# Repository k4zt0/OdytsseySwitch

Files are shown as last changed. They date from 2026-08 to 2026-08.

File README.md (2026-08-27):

# Odytssey Switch

Five-key wireless macropad built around an ESP32-S3, with a 0.96" OLED and a
thumbstick. Reaches a host over USB HID, BLE HID, or Wi-Fi, and can drive other
gear through its I2C, UART and addressable-LED outputs.

## Hardware

| Block | Part |
| --- | ---- |
| MCU | ESP32-S3-WROOM-1 — BLE 5, Wi-Fi 4, native USB, pre-certified module |
| Keys | 5 x Kailh MX hotswap sockets on GPIO 4, 5, 6, 7, 15 |
| Stick | 2-axis thumbstick, X on IO1 and Y on IO2 (ADC1 only), press on IO16 |
| Display | SSD1306 0.96" 128x64 over I2C0 (SDA IO8, SCL IO9) |
| Outputs | Qwiic I2C port, WS2812 strip header, UART0 + 4 spare GPIO |
| Power | USB-C bus powered, AP2112K-3.3 LDO, USBLC6-2SC6 ESD array |

Both analogue axes sit on ADC1 because ADC2 stops working once the radio is
transmitting. The thumbstick is fed 3V3 rather than 5V so its wiper range
matches the ADC full scale.

## Board

- 112 x 102 mm, 2 layer FR-4, 1.6 mm, 3 mm corner radius
- Front carries the keys and the two module sockets; every other part is on the
  back, so the panel reflows from one side only
- No through-hole parts — the module connectors are SMD sockets, so assembly
  needs no soldering at all
- Routed on both layers, 345 tracks and 207 vias, ground pours stitched
  together and bonded solid to pads rather than through thermal spokes
- The ESP32 module's antenna overhangs the left edge; keep metal away from it
- Ground pours on both layers, stitched with vias

## Assembly

Order with SMT assembly. Nothing needs soldering afterwards:

1. Plug the OLED module into J2
2. Plug the thumbstick module into J7
3. Drop five MX switches into the hotswap sockets
4. Fit keycaps

Buy modules that already have their pin headers soldered on.

## Fabrication

`fab/` holds Gerbers, Excellon drill files, the drill map, the `.gbrjob`,
pick-and-place data and the BOM.

| Setting | Value |
| --- | ----- |
| Base material | FR-4, TG130-140 |
| Layers | 2 |
| Thickness | 1.6 mm |
| Panel | single PCB |
| Surface finish | ENIG |
| Min hole | 0.2 mm |

The 1.6 mm thickness is not optional: MX hotswap sockets are cut for it.

## Layout

Third-party footprints come from [kiswitch](https://github.com/kiswitch/kiswitch);
only `Switch_Keyboard_Hotswap_Kailh.pretty` is vendored here, under `libs/`.
`fp-lib-table` points at it with `${KIPRJMOD}`.

## Status

Complete and ready to order.

| Check | Result |
| ----- | --- |
| ERC | 0 errors |
| DRC | 0 errors |
| Unconnected | 0 |
| Schematic parity | 0 issues |
| Netlist vs. design intent | checked pin by pin, no mismatch |

Two DRC warnings remain and are both expected: the ESP32 module's silkscreen
crosses the left board edge by 0.15 mm, which is the deliberate antenna
overhang, and sixteen footprints differ from their library copies, which has no
bearing on fabrication.

The autorouter did not length-match the USB differential pair. At USB 2.0 Full
Speed that is not a problem in practice, but tidy those two traces by hand if
you want it right.

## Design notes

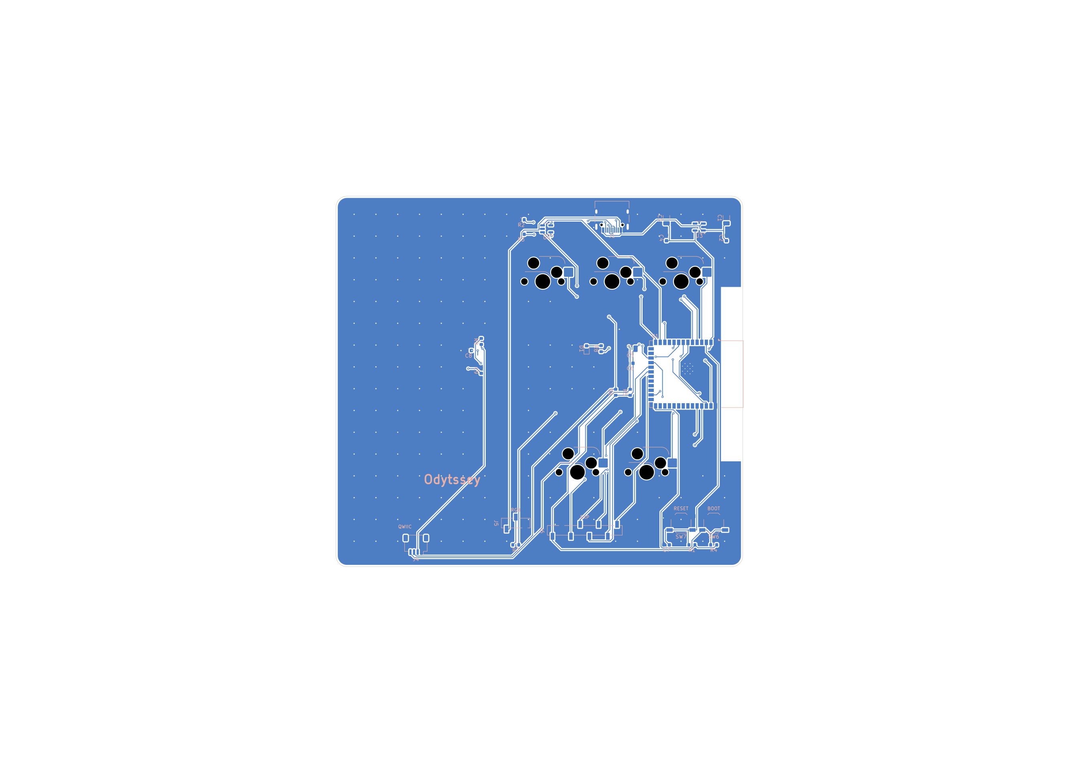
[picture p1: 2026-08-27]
board-back.png

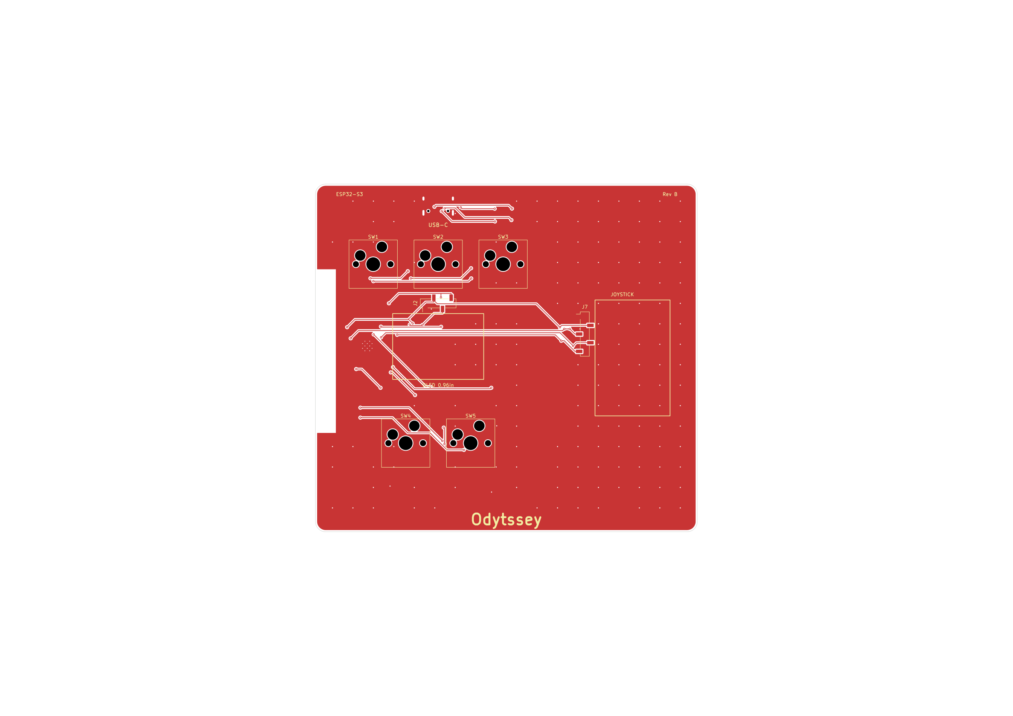
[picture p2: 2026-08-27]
board-front.png

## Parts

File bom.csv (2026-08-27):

Reference | Value | Footprint | Description | QUANTITY
C1 | 10uF | Capacitor_SMD:C_1206_3216Metric | LDO input bulk | 1
C2,C4,C7 | 1uF | Capacitor_SMD:C_0603_1608Metric | EN power-on reset delay,LDO input,LDO output | 3
C3,C5 | 22uF | Capacitor_SMD:C_1206_3216Metric | LDO output bulk,Module supply bulk - covers WiFi TX peaks | 2
C6 | 100nF | Capacitor_SMD:C_0603_1608Metric | Decoupling - module 3V3 pin | 1
D1 | LED | LED_SMD:LED_0603_1608Metric | Status LED | 1
J1 | USB-C | Connector_USB:USB_C_Receptacle_HRO_TYPE-C-31-M-12 | USB 2.0 Type-C receptacle, 16 pin | 1
J2 | OLED_I2C | Connector_PinHeader_2.54mm:PinHeader_1x04_P2.54mm_Vertical | SSD1306 0.96in 128x64 OLED module (GND/VCC/SCL/SDA) | 1
J4 | QWIIC_I2C | Connector_JST:JST_SH_SM04B-SRSS-TB_1x04-1MP_P1.00mm_Horizontal | Qwiic/STEMMA QT I2C output port (GND/3V3/SDA/SCL) | 1
J5 | RGB_OUT | Connector_PinHeader_2.54mm:PinHeader_1x03_P2.54mm_Vertical | Addressable LED strip output (5V/DIN/GND) | 1
J6 | EXPANSION | Connector_PinHeader_2.54mm:PinHeader_1x08_P2.54mm_Vertical | Expansion header - UART0 TX/RX and 4 spare GPIO | 1
R1,R4 | 10k | Resistor_SMD:R_0603_1608Metric | EN pull-up,IO0 strapping pull-up | 2
R2,R3 | 5.1k | Resistor_SMD:R_0603_1608Metric | Type-C CC pull-down (UFP) | 2
R5,R6 | 4.7k | Resistor_SMD:R_0603_1608Metric | I2C pull-up | 2
R7 | 330 | Resistor_SMD:R_0603_1608Metric | RGB data-line series damping | 1
R8 | 1k | Resistor_SMD:R_0603_1608Metric | Status LED current limit | 1
SW1-SW5 | MX_HOTSWAP | Switch_Keyboard_Hotswap_Kailh:SW_Hotswap_Kailh_MX_1.00u | Kailh MX hotswap socket, key 1,Kailh MX hotswap socket, key 2,Kailh MX hotswap socket, key 3,Kailh MX hotswap socket, key 4,Kailh MX hotswap socket, key 5 | 5
SW6 | BOOT | Button_Switch_SMD:SW_SPST_TL3342 | BOOT - hold at reset for USB download mode | 1
SW7 | RESET | Button_Switch_SMD:SW_SPST_TL3342 | Reset button | 1
U1 | ESP32-S3-WROOM-1 | RF_Module:ESP32-S3-WROOM-1 | Xtensa LX7 dual core - BLE 5, WiFi 4, native USB (pre-certified module) | 1
U3 | AP2112K-3.3 | Package_TO_SOT_SMD:SOT-23-5 | 600 mA 3.3 V LDO | 1
U4 | USBLC6-2SC6 | Package_TO_SOT_SMD:SOT-23-6 | USB data-line ESD protection array | 1

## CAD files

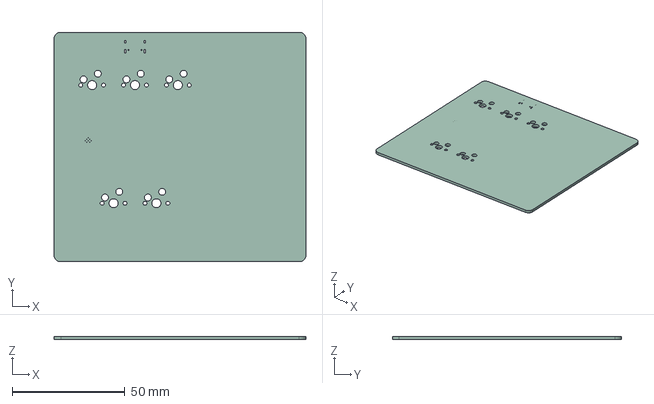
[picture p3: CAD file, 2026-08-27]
OdytsseySwitch.step
112.0 x 102.0 x 1.51 mm

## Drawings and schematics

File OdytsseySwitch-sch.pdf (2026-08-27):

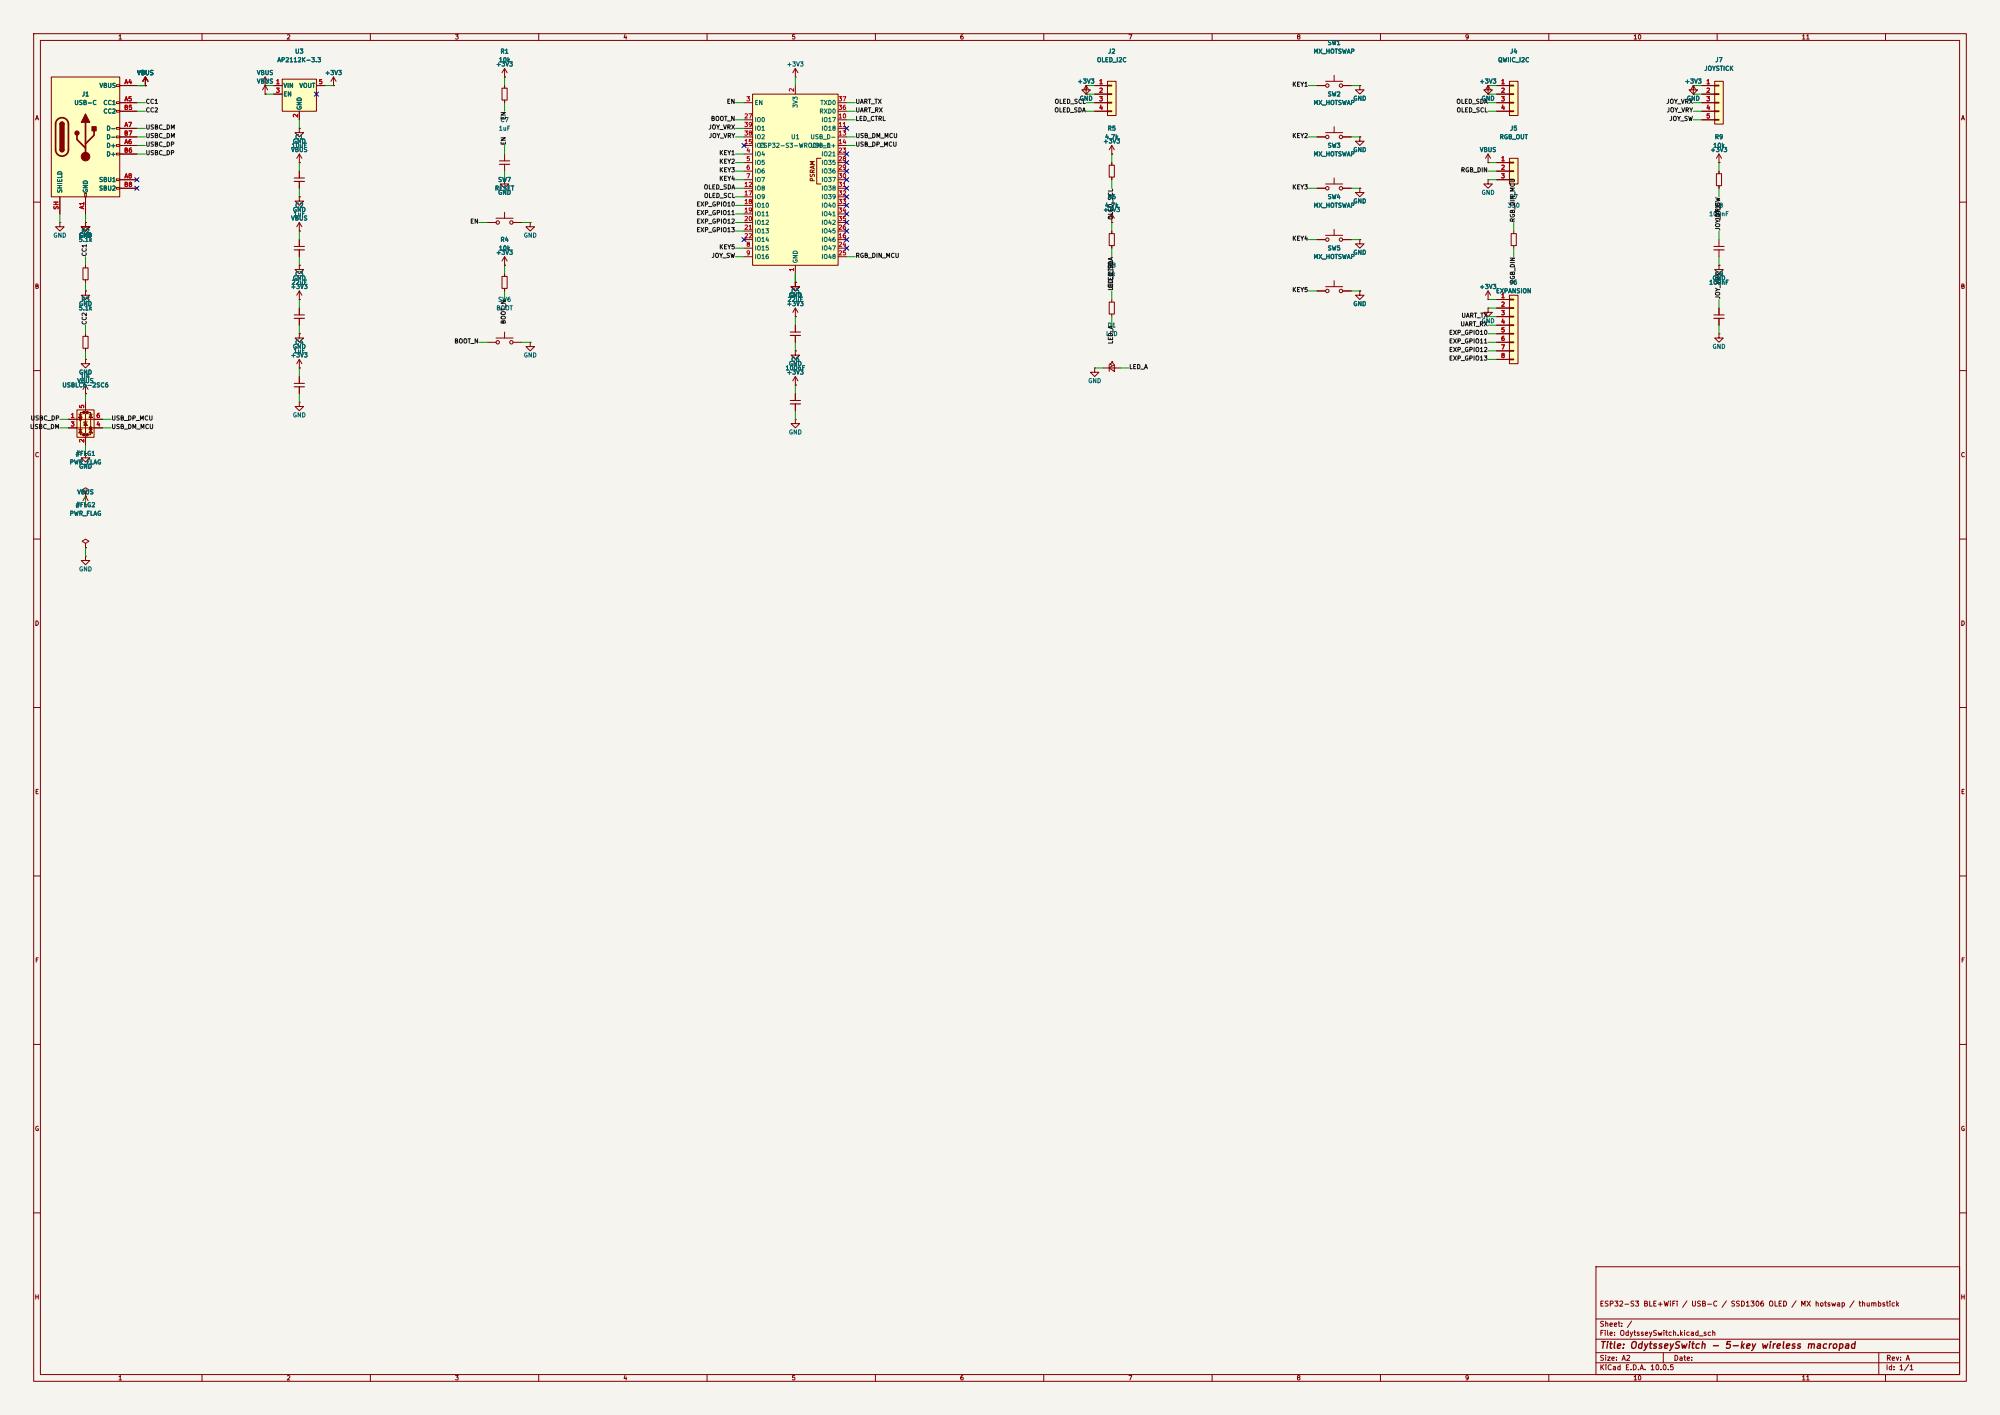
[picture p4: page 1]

ESP32-S3 BLE+WiFi / USB-C / SSD1306 OLED / MX hotswap / thumbstick

Sheet: /
File: OdytsseySwitch.kicad_sch
Title: OdytsseySwitch - 5-key wireless macropad

Size: A2 | Rev: A
KiCad E.D.A. 10.0.5 | Id: 1/1

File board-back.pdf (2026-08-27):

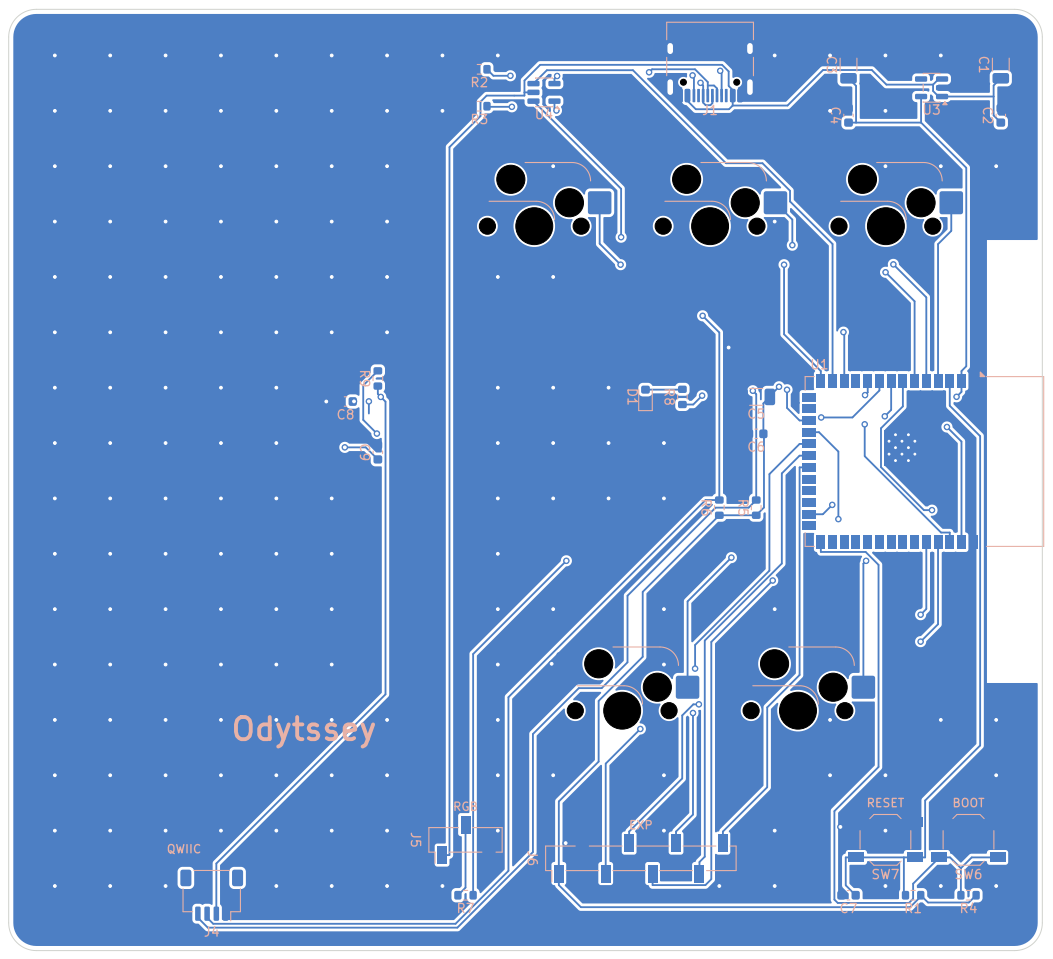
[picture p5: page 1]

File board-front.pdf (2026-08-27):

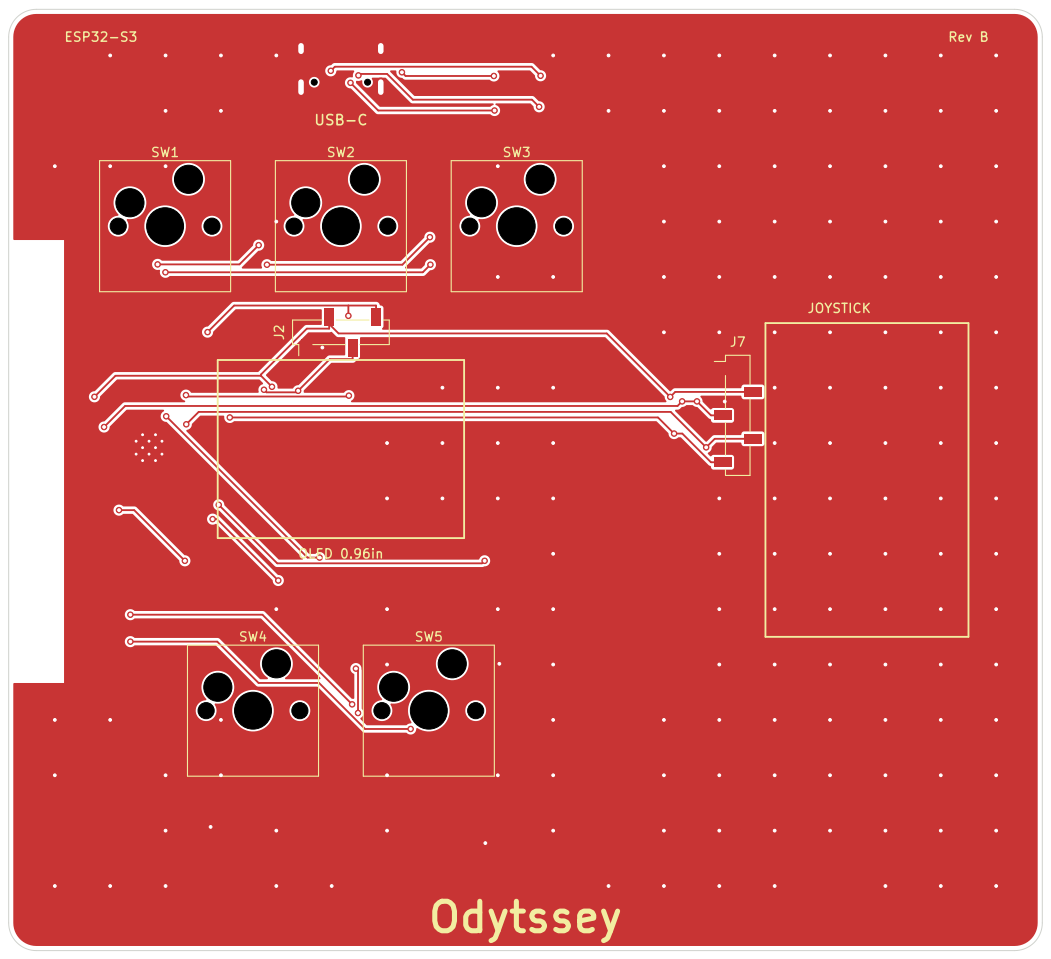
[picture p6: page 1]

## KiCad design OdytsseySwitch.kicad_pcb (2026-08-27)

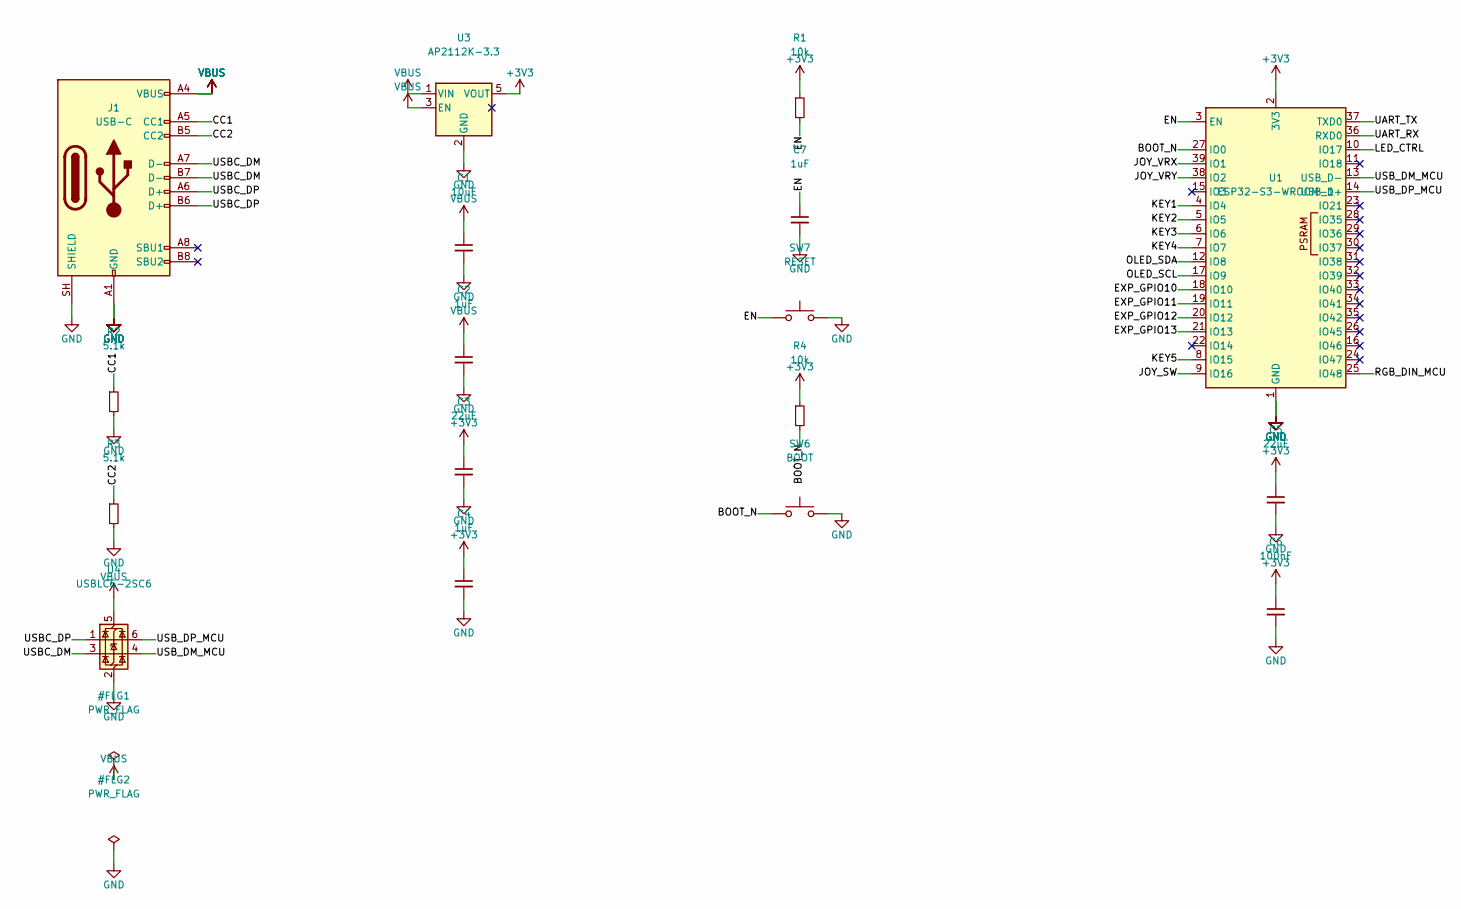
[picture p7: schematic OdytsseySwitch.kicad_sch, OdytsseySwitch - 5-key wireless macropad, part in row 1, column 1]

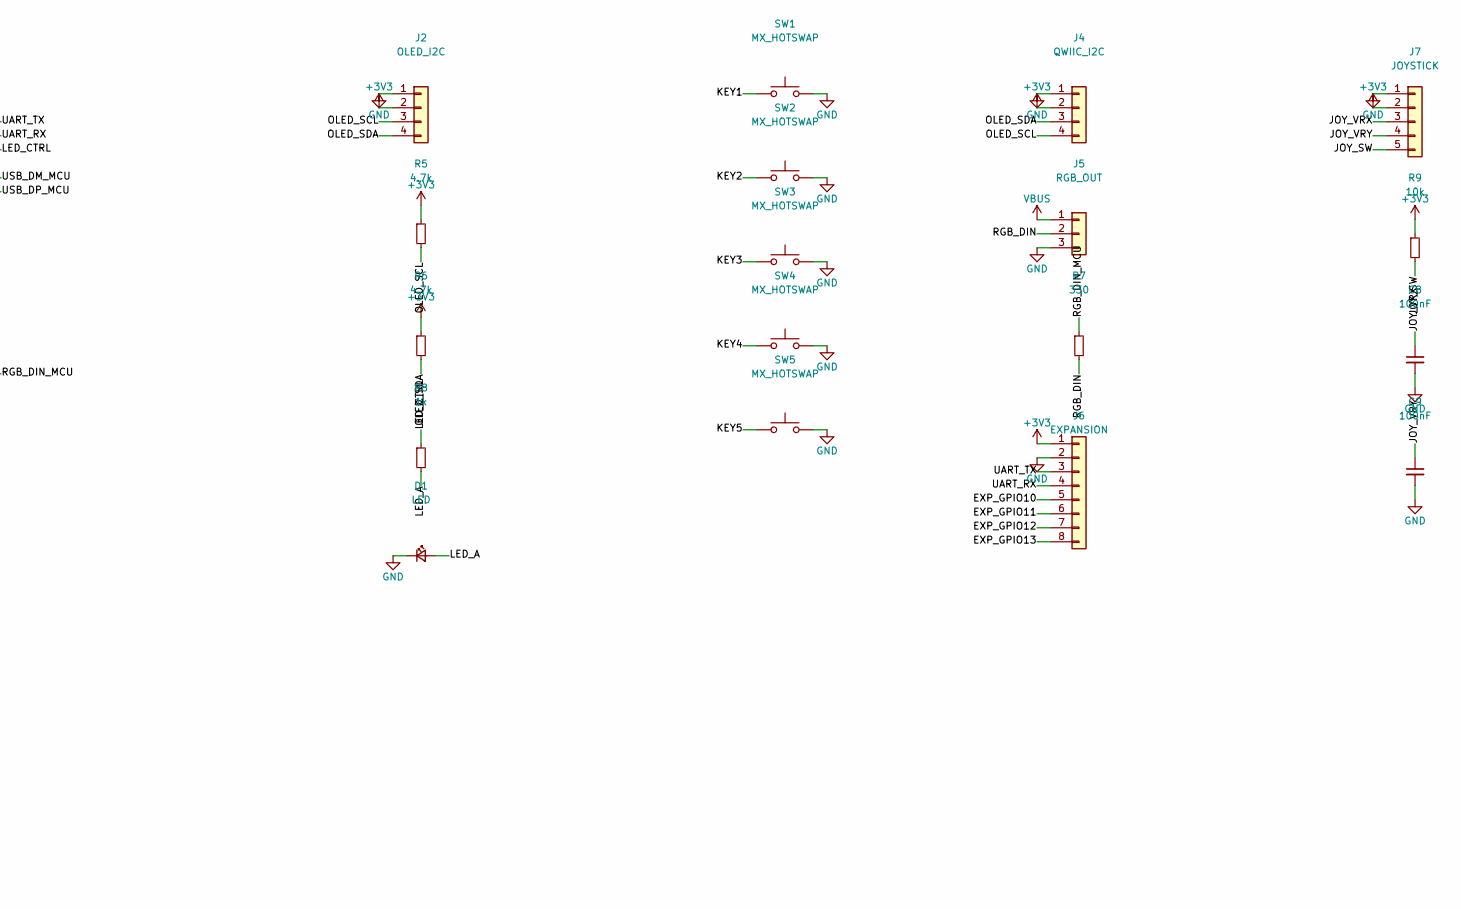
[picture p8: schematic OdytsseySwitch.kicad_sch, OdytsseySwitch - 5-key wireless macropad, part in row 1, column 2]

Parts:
C1: 10uF; C_1206_3216Metric
C2, C4, C7: 1uF; C_0603_1608Metric
C3, C5: 22uF; C_1206_3216Metric
C6, C8, C9: 100nF; C_0603_1608Metric
D1: LED; LED_0603_1608Metric
J1: USB-C; USB_C_Receptacle_HRO_TYPE-C-31-M-12
J2: OLED_I2C; PinSocket_1x04_P2.54mm_Vertical_SMD_Pin1Left
J4: QWIIC_I2C; JST_SH_SM04B-SRSS-TB_1x04-1MP_P1.00mm_Horizontal
J5: RGB_OUT; PinSocket_1x03_P2.54mm_Vertical_SMD_Pin1Left
J6: EXPANSION; PinSocket_1x08_P2.54mm_Vertical_SMD_Pin1Left
J7: JOYSTICK; PinSocket_1x05_P2.54mm_Vertical_SMD_Pin1Left
R1, R4, R9: 10k; R_0603_1608Metric
R2, R3: 5.1k; R_0603_1608Metric
R5, R6: 4.7k; R_0603_1608Metric
R7: 330; R_0603_1608Metric
R8: 1k; R_0603_1608Metric
SW1, SW2, SW3, SW4, SW5: MX_HOTSWAP; SW_Hotswap_Kailh_MX_1.00u
SW6: BOOT; SW_SPST_TL3342
SW7: RESET; SW_SPST_TL3342
U1: ESP32-S3-WROOM-1
U3: AP2112K-3.3; SOT-23-5
U4: USBLC6-2SC6; SOT-23-6

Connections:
+3V3: C3.1, C4.1, C5.1, C6.1, J2.2, J4.2, J6.1, J7.2, R1.1, R4.1, R5.1, R6.1, R9.1, U1.2 (3V3), U3.5 (VOUT)
/BOOT_N: R4.2, SW6.1, U1.27 (IO0)
/CC1: J1.A5 (CC1), R2.1
/CC2: J1.B5 (CC2), R3.1
/EN: C7.1, R1.2, SW7.1, U1.3 (EN)
/EXP_GPIO10: J6.5, U1.18 (IO10)
/EXP_GPIO11: J6.6, U1.19 (IO11)
/EXP_GPIO12: J6.7, U1.20 (IO12)
/EXP_GPIO13: J6.8, U1.21 (IO13)
/JOY_SW: J7.5, R9.2, U1.9 (IO16)
/JOY_VRX: C8.1, J7.3, U1.39 (IO1)
/JOY_VRY: C9.1, J7.4, U1.38 (IO2)
/KEY1: SW1.1, U1.4 (IO4)
/KEY2: SW2.1, U1.5 (IO5)
/KEY3: SW3.1, U1.6 (IO6)
/KEY4: SW4.1, U1.7 (IO7)
/KEY5: SW5.1, U1.8 (IO15)
/LED_A: D1.2 (A), R8.2
/LED_CTRL: R8.1, U1.10 (IO17)
/OLED_SCL: J2.3, J4.4, R5.2, U1.17 (IO9)
/OLED_SDA: J2.4, J4.3, R6.2, U1.12 (IO8)
/RGB_DIN: J5.2, R7.2
/RGB_DIN_MCU: R7.1, U1.25 (IO48)
/UART_RX: J6.4, U1.36 (RXD0)
/UART_TX: J6.3, U1.37 (TXD0)
/USBC_DM: J1.A7 (D-), J1.B7 (D-), U4.3 (I/O2)
/USBC_DP: J1.A6 (D+), J1.B6 (D+), U4.1 (I/O1)
/USB_DM_MCU: U1.13 (USB_D-), U4.4 (I/O2)
/USB_DP_MCU: U1.14 (USB_D+), U4.6 (I/O1)
GND: C1.2, C2.2, C3.2, C4.2, C5.2, C6.2, C7.2, C8.2, C9.2, D1.1 (K), J1.A1 (GND), J1.A12 (GND), J1.B1 (GND), J1.B12 (GND), J1.SH (SHIELD), J2.1, J4.1, J5.3, J6.2, J7.1, R2.2, R3.2, SW1.2, SW2.2, SW3.2, SW4.2, SW5.2, SW6.2, SW7.2, U1.1 (GND), U1.40 (GND), U1.41 (GND), U3.2 (GND), U4.2 (GND)
VBUS: C1.1, C2.1, J1.A4 (VBUS), J1.A9 (VBUS), J1.B4 (VBUS), J1.B9 (VBUS), J5.1, U3.1 (VIN), U3.3 (EN), U4.5 (VBUS)

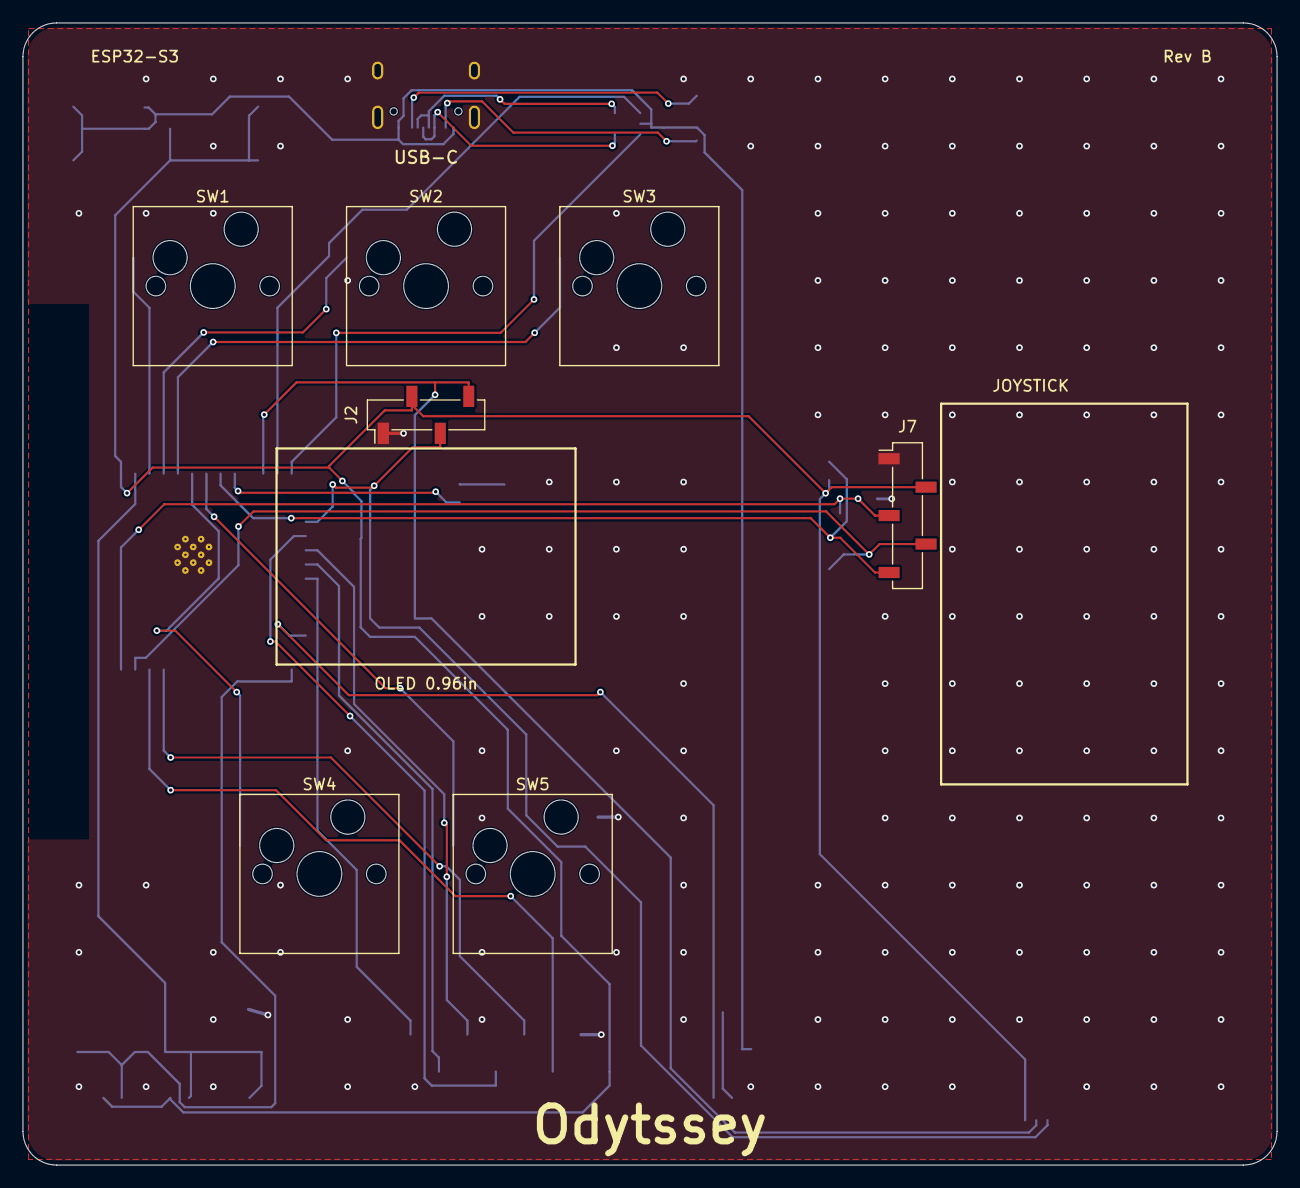
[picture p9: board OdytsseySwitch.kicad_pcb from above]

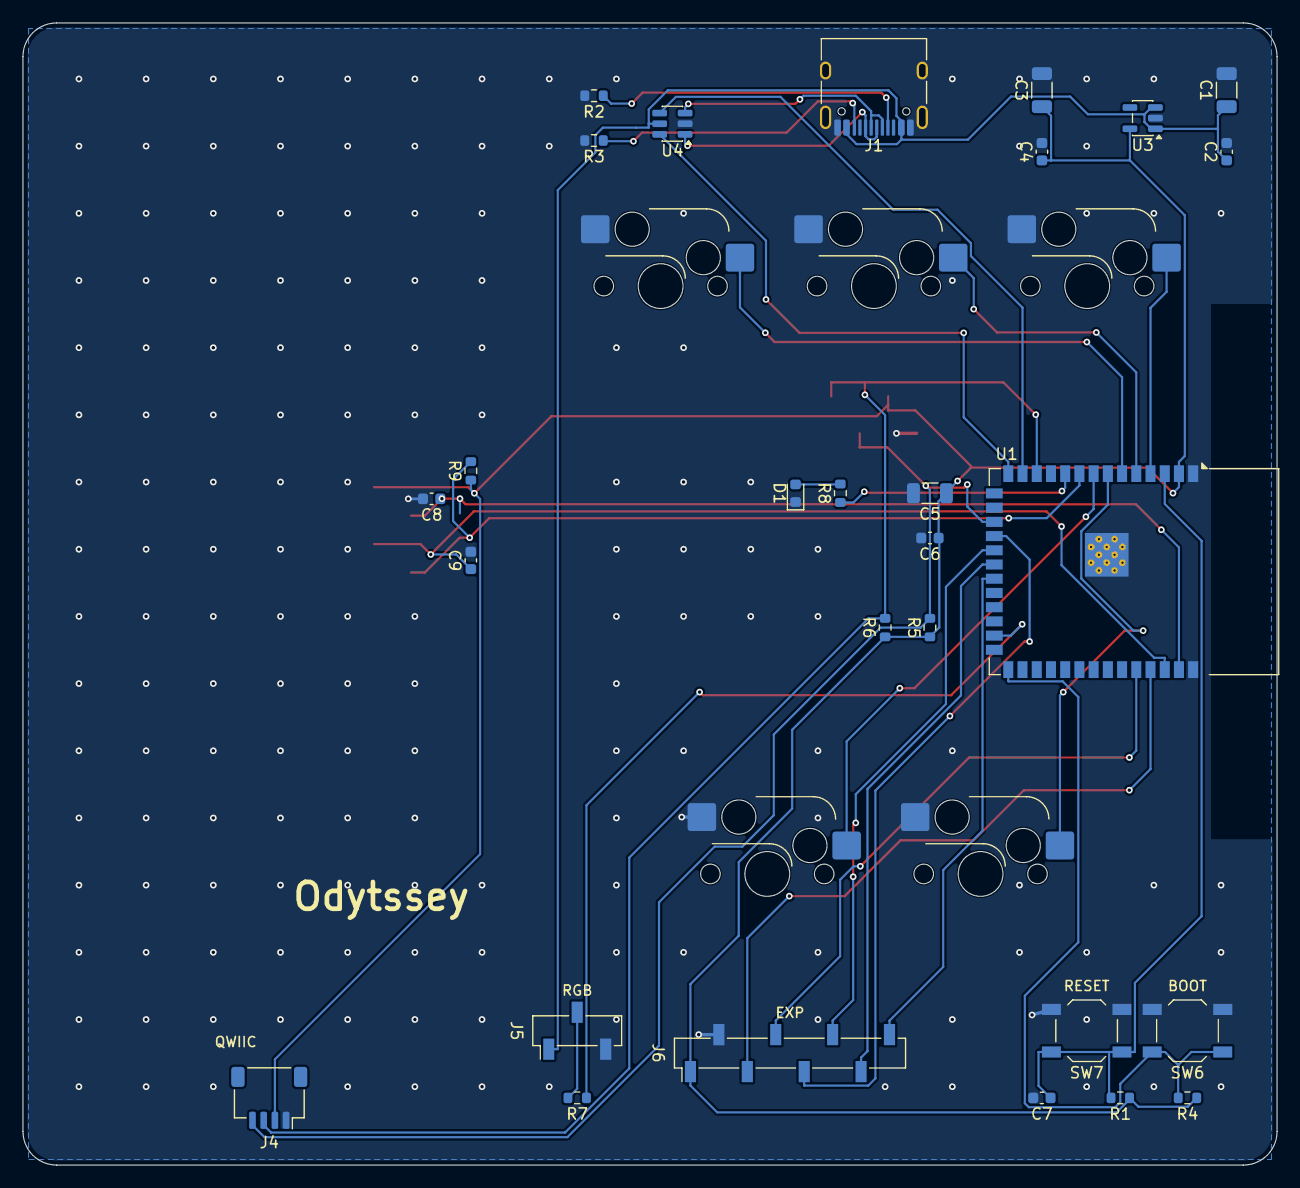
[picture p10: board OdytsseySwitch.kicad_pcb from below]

Board: 2 copper layers, 112.0 x 102.0 mm, 35 parts (28 on the bottom side), 31 nets.

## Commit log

2026-08-27 Add Odytssey Switch: ESP32-S3 wireless macropad
    Five MX hotswap keys, a 0.96" SSD1306 OLED and a two-axis thumbstick on an
    ESP32-S3-WROOM-1, bus powered over USB-C.
    The analogue axes are on ADC1 because ADC2 is unusable while the radio is
    transmitting, and the stick runs from 3V3 so its output matches the ADC range.
    Module connectors are SMD sockets rather than pin headers, which keeps the
    board free of through-hole parts and means it needs no soldering after
    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
    [OdytsseySwitch-B_Cu.gbr, OdytsseySwitch-B_Mask.gbr, OdytsseySwitch-B_Paste.gbr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]
2026-08-27 Route the board and clear DRC
    Swaps the module connectors from through-hole pin headers to SMD sockets, which
    removes the last through-hole parts and drops the assembly's soldering step
    entirely. It also fixes a real defect: the board previously carried male pin
    headers facing modules that are themselves male, so nothing would have plugged
    in.
    Routing is autorouted with every net connected, then repaired by hand where the
    router left gaps. Ground pours bond solid to pads instead of through thermal
    spokes, since starved spokes were stranding pads on a reflow-assembled board,
    and 160 stitching vias tie the two pours together. C8 had to move: the router
    sealed it into a pocket its ground pad c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
    [OdytsseySwitch-B_Cu.gbr, OdytsseySwitch-B_Mask.gbr, OdytsseySwitch-B_Paste.gbr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]
2026-08-27 Pull a stitching via clear of the USB-C shield hole
    Measuring the design against typical fab capability turned up one hole pair at
    0.286 mm, well under the 0.5 mm most houses ask for: a ground stitching via had
    landed beside J1's shield post. Removing it costs nothing, since the pours stay
    tied through the remaining two hundred vias and connectivity is unchanged.
    Tightest hole spacing is now 0.440 mm, and every pair at that figure is inside
    a Kailh hotswap footprint, where the peg and stem holes are milled rather than
    drilled.
    Fabrication outputs regenerated.
    [OdytsseySwitch-B_Cu.gbr, OdytsseySwitch-B_Mask.gbr, OdytsseySwitch-B_Paste.gbr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]
